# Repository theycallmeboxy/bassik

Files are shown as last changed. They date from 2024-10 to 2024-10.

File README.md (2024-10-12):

# Bassik
*10u ortho alpha uniform traditional stagger keyboard*

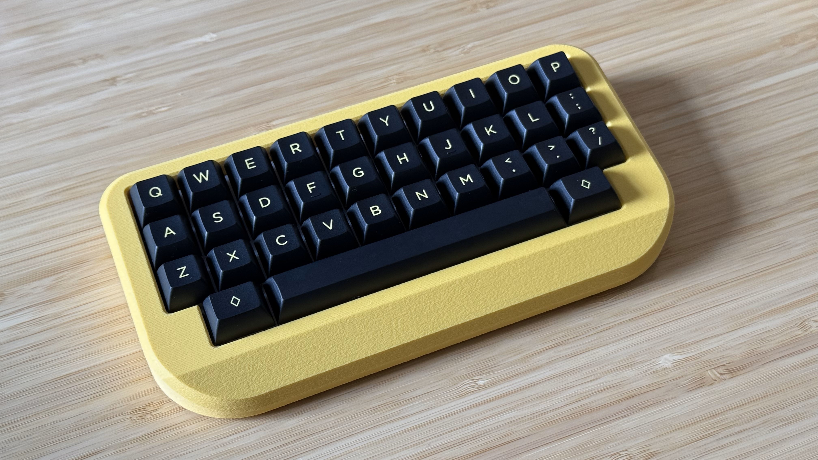
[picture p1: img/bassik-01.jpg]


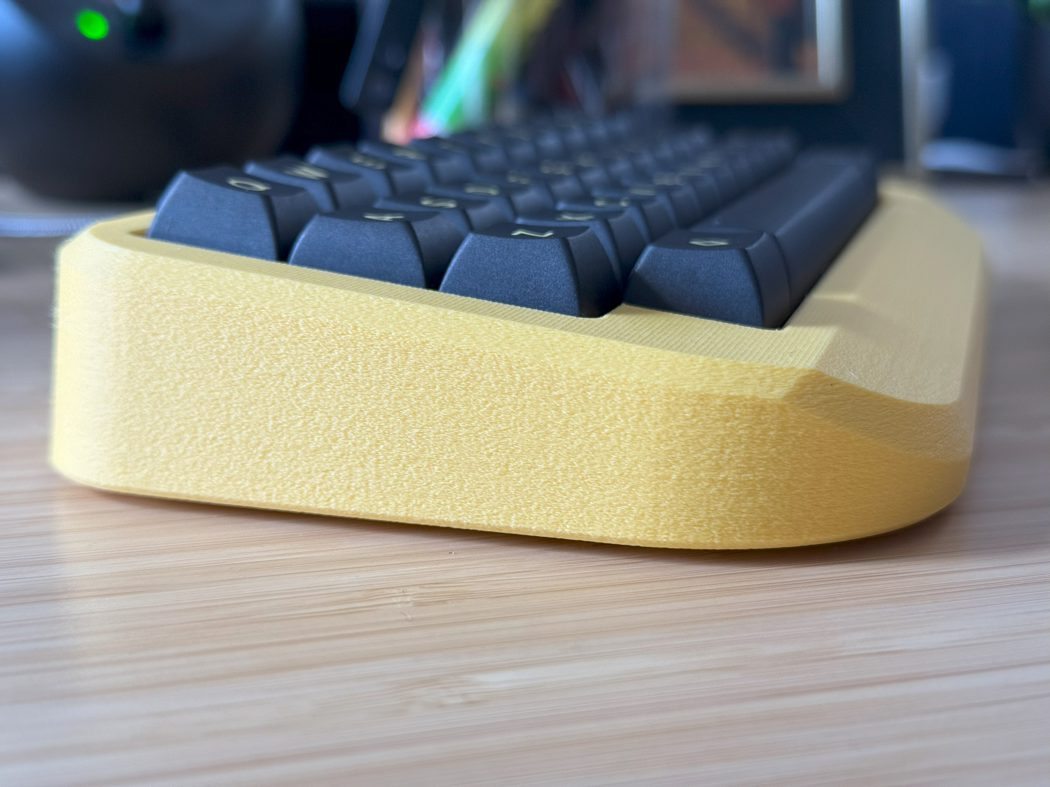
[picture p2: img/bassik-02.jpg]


**[KLE](https://www.keyboard-layout-editor.com/##@_name=Bassik%3B&@=0,0&=0,1&=0,2&=0,3&=0,4&=0,5&=0,6&=0,7&=0,8&=0,9&_x:0.25&c=%2348c763%3B&=1,0%0A%0A%0A0,1&=1,1%0A%0A%0A0,1&=1,2%0A%0A%0A0,1&=1,3%0A%0A%0A0,1&=1,4%0A%0A%0A0,1&=1,5%0A%0A%0A0,1&=1,6%0A%0A%0A0,1&=1,7%0A%0A%0A0,1&=1,8%0A%0A%0A0,1&=1,9%0A%0A%0A0,1%3B&@=1,0%0A%0A%0A0,0&=1,1%0A%0A%0A0,0&=1,2%0A%0A%0A0,0&=1,3%0A%0A%0A0,0&=1,4%0A%0A%0A0,0&=1,5%0A%0A%0A0,0&=1,6%0A%0A%0A0,0&=1,7%0A%0A%0A0,0&=1,8%0A%0A%0A0,0&=1,9%0A%0A%0A0,0&_x:0.25&w:1.5%3B&=2,0%0A%0A%0A0,1&=2,2%0A%0A%0A0,1&=2,3%0A%0A%0A0,1&=2,4%0A%0A%0A0,1&=2,5%0A%0A%0A0,1&=2,6%0A%0A%0A0,1&=2,7%0A%0A%0A0,1&=2,8%0A%0A%0A0,1&_w:1.5%3B&=2,9%0A%0A%0A0,1%3B&@=2,0%0A%0A%0A0,0&=2,1%0A%0A%0A0,0&=2,2%0A%0A%0A0,0&=2,3%0A%0A%0A0,0&=2,4%0A%0A%0A0,0&=2,5%0A%0A%0A0,0&=2,6%0A%0A%0A0,0&=2,7%0A%0A%0A0,0&=2,8%0A%0A%0A0,0&=2,9%0A%0A%0A0,0%3B&@_y:-0.75&x:10.25&w:1.25%3B&=1,0%0A%0A%0A0,2&=1,1%0A%0A%0A0,2&=1,2%0A%0A%0A0,2&=1,3%0A%0A%0A0,2&=1,4%0A%0A%0A0,2&=1,5%0A%0A%0A0,2&=1,6%0A%0A%0A0,2&=1,7%0A%0A%0A0,2&_w:1.75%3B&=1,9%0A%0A%0A0,2%3B&@_y:-0.25&x:0.63&c=%23ffeb8a&w:1.25%3B&=3,0%0A%0A%0A1,0&_w:6.25%3B&=3,4%0A%0A%0A1,0&_x:1.7763568394002505e-15&w:1.25%3B&=3,8%0A%0A%0A1,0%3B&@_y:-0.75&x:10.25&c=%2348c763&w:1.5%3B&=2,0%0A%0A%0A0,2&=2,2%0A%0A%0A0,2&=2,3%0A%0A%0A0,2&=2,4%0A%0A%0A0,2&=2,5%0A%0A%0A0,2&=2,6%0A%0A%0A0,2&=2,7%0A%0A%0A0,2&=2,8%0A%0A%0A0,2&_w:1.5%3B&=2,9%0A%0A%0A0,2%3B&@_x:0.63&c=%23ffeb8a%3B&=3,0%0A%0A%0A1,1&=3,1%0A%0A%0A1,1&=3,2%0A%0A%0A1,1&_w:2.75%3B&=3,4%0A%0A%0A1,1&=3,6%0A%0A%0A1,1&=3,7%0A%0A%0A1,1&_x:1.7763568394002505e-15%3B&=3,8%0A%0A%0A1,1%3B&@_y:-0.75&x:10.25&c=%2348c763&w:1.25%3B&=1,0%0A%0A%0A0,3&=1,1%0A%0A%0A0,3&=1,2%0A%0A%0A0,3&=1,3%0A%0A%0A0,3&=1,4%0A%0A%0A0,3&=1,5%0A%0A%0A0,3&=1,6%0A%0A%0A0,3&=1,7%0A%0A%0A0,3&_w:1.75%3B&=1,9%0A%0A%0A0,3%3B&@_x:0.63&c=%23ffeb8a&w:1.25%3B&=3,0%0A%0A%0A1,2&=3,1%0A%0A%0A1,2&_w:2.25%3B&=3,3%0A%0A%0A1,2&_w:2%3B&=3,5%0A%0A%0A1,2&=3,7%0A%0A%0A1,2&_x:1.7763568394002505e-15&w:1.25%3B&=3,8%0A%0A%0A1,2&_x:0.8699999999999992&c=%2348c763&w:1.75%3B&=2,0%0A%0A%0A0,3&=2,2%0A%0A%0A0,3&=2,3%0A%0A%0A0,3&=2,4%0A%0A%0A0,3&=2,5%0A%0A%0A0,3&=2,6%0A%0A%0A0,3&=2,7%0A%0A%0A0,3&=2,8%0A%0A%0A0,3&_w:1.25%3B&=2,9%0A%0A%0A0,3)**

## Production Files:
> [!CAUTION]
> I will assume no responsibility for any cost, damage, or sads resulting from trying to make one of my dumb projects. This project has no implicit support, neither moral nor technical.
> 
> **I'm not a doctor. This is not medical advice. I'm also only a network engineer. You assume all liability in using or reproducing these files.**

Case:
- [Case .stl file](https://github.com/theycallmeboxy/bassik/blob/main/models/case/bassik-case.stl)
- [Case .step file](https://github.com/theycallmeboxy/bassik/blob/main/models/case/bassik-case.step)

Plate:
- [Ortho stagger 6.25u spacebar plate .dxf file](https://github.com/theycallmeboxy/bassik/blob/main/models/plate/ortho-625.dxf)
- [Ortho stagger 2.75u spacebar plate .dxf file](https://github.com/theycallmeboxy/bassik/blob/main/models/plate/ortho-275.dxf)
- [Ortho stagger 2.25-2.00 spacebars plate .dxf file](https://github.com/theycallmeboxy/bassik/blob/main/models/plate/ortho-225200.dxf)
- [Ortho stagger universal plate .dxf file](https://github.com/theycallmeboxy/bassik/blob/main/models/plate/ortho-universal.dxf)
- [Alpha stagger 6.25u spacebar plate .dxf file](https://github.com/theycallmeboxy/bassik/blob/main/models/plate/alpha-625.dxf)
- [Alpha stagger 2.75u spacebar plate .dxf file](https://github.com/theycallmeboxy/bassik/blob/main/models/plate/alpha-275.dxf)
- [Alpha stagger 2.25-2.00 spacebars plate .dxf file](https://github.com/theycallmeboxy/bassik/blob/main/models/plate/alpha-225200.dxf)
- [Alpha stagger universal plate .dxf file](https://github.com/theycallmeboxy/bassik/blob/main/models/plate/alpha-universal.dxf)
- [Uniform stagger 6.25u spacebar plate .dxf file](https://github.com/theycallmeboxy/bassik/blob/main/models/plate/uni-625.dxf)
- [Uniform stagger 2.75u spacebar plate .dxf file](https://github.com/theycallmeboxy/bassik/blob/main/models/plate/uni-275.dxf)
- [Uniform stagger 2.25-2.00 spacebars plate .dxf file](https://github.com/theycallmeboxy/bassik/blob/main/models/plate/uni-225200.dxf)
- [Uniform stagger universal plate .dxf file](https://github.com/theycallmeboxy/bassik/blob/main/models/plate/uni-universal.dxf)
- [Traditional stagger 6.25u spacebar plate .dxf file](https://github.com/theycallmeboxy/bassik/blob/main/models/plate/trad-625.dxf)
- [Traditional stagger 2.75u spacebar plate .dxf file](https://github.com/theycallmeboxy/bassik/blob/main/models/plate/uni-275.dxf)
- [Traditional stagger 2.25-2.00 spacebars plate .dxf file](https://github.com/theycallmeboxy/bassik/blob/main/models/plate/trad-225200.dxf)
- [Traditional stagger universal plate .dxf file](https://github.com/theycallmeboxy/bassik/blob/main/models/plate/trad-universal.dxf)

PCB:
> [!NOTE]
> Version 1 was produced (as prototype 1) without any identified issues.  The gerbers were regenerated to indicate version 1 on the silk and have retained the original BOM and positions files.  I have not produced these files yet, but they should be good to go.

- [PCB gerbers .zip file](https://github.com/theycallmeboxy/bassik/blob/main/pcb/bassik%20v1/production/bassik.zip)
- [BOM .csv file](https://github.com/theycallmeboxy/bassik/blob/main/pcb/bassik%20v1/production/bom.csv)
- [Positions .csv file](https://github.com/theycallmeboxy/bassik/blob/main/pcb/bassik%20v1/production/positions.csv)

Firmware:
- [VIAL Firmware .bin file](https://github.com/theycallmeboxy/bassik/blob/main/firmware/vial/binary/boxy_bassik_vial.bin)
  
## Build Notes:

I have made with FDM to good effect.

**Additional materials:**
 
  - About 16" of .139" (3.53mm) cross section o-ring cord [like this 50A cord](https://www.theoringstore.com/store/index.php?main_page=product_info&cPath=117_527&products_id=18618) or [this 70A cord](https://www.theoringstore.com/store/index.php?main_page=product_info&cPath=117_119&products_id=5058); if you don't want to buy bulk cord, you can cut up an o-ring of like 6" or bigger diameter.
  - 4 SKUF feet like these  [like these](https://keeb.io/products/skuf-silicone-rubber-keyboard-feet).

**Build instructions:**

1. Apply feet to the cutouts.
2. Install stabs if you're into that. 
3. Install switches into the plate and PCB.
4. Solder it up.
5. Friction fit the o-ring cord between the plate and PCB in the positions highlighted in red:

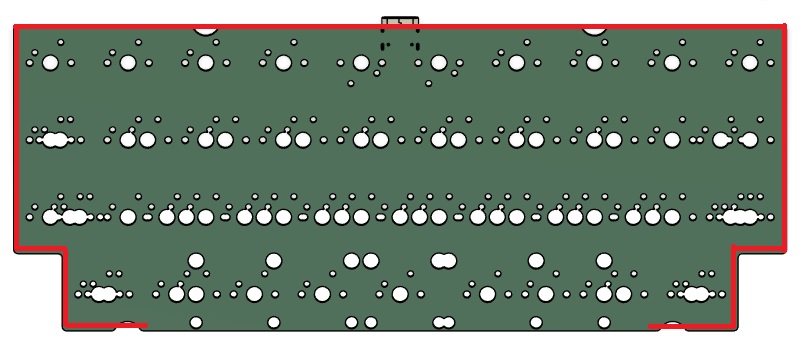
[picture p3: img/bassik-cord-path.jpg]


6. Insert the assembled PCB USB port first into the case at an angle, aligning the port with the cutout.
7. Press the top of the PCB in place, then press in the bottom side (if your cord isn't fully seated, sticks out on the corners, or otherwise catches going in, grab some tweezers and help it stay in between the plate and PCB). 
8. If you need to remove the PCB, pull a few caps off and use a switch puller on the soldered switches.

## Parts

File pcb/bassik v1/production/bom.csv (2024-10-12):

Designator | Footprint | Quantity | Value | LCSC Part #
BOOT1, RST1 | SW_SPST_TL3342 | 2 | SW_SPST | C318884
C1, C3, C4, C5, C6, C7, C8 | 0402 | 7 | 100nF | C1525
C10, C9 | 0402 | 2 | 1uF | C52923
C2 | 0603 | 1 | 10uF | C19702
D1, D10, D11, D12, D13, D14, D15, D16, D17, D18, D19, D2, D20, D21, D22, D23, D24, D25, D26, D27, D28, D29, D3, D30, D31, D32, D33, D34, D35, D36, D37, D38, D39, D4, D5, D6, D7, D8, D9 | D_SOD-123 | 39 | D | C81598
F1 | 1206 | 1 | 500mA | C369160
J1 | USB_C_Receptacle_HRO_TYPE-C-31-M-12 | 1 | USB_C_Receptacle_USB2.0 | C165948
R1, R2, R3, R4 | 0402 | 4 | 5.1k | C25905
U1 | LQFP-48_7x7mm_P0.5mm | 1 | STM32F072CBT6 | C81720
U2 | SOT-143 | 1 | PRTR5V0U2X | C2827688
U3 | SOT-23 | 1 | XC6206PxxxMR-Regulator_Linear | C5446

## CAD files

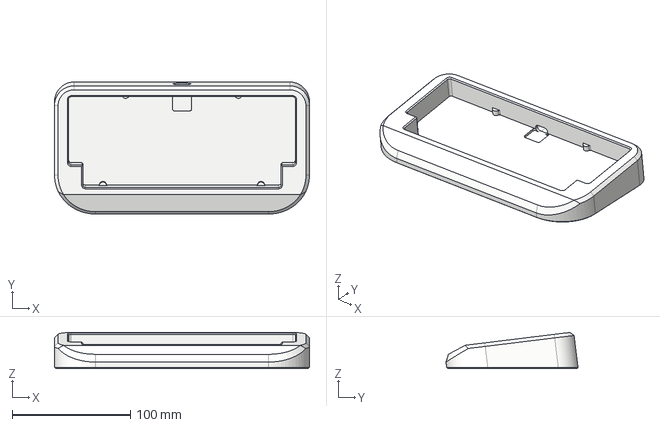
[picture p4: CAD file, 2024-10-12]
models/case/bassik-case.step
215.6 x 111.6 x 30.6 mm

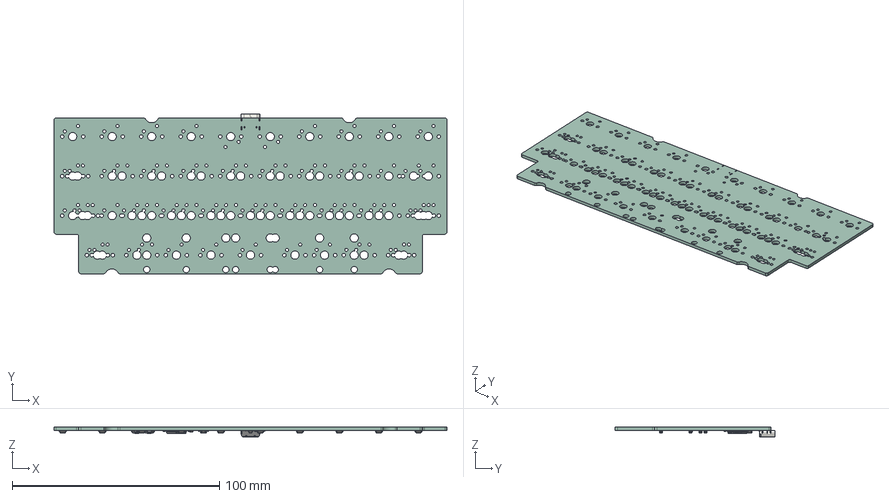
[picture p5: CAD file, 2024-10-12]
models/pcb/bassik.step
189.5 x 76.9 x 4.85 mm
C_0402_1005Metric x 9
D_SOD_123 x 39
R_0402_1005Metric x 4
SW_SPST_TL3342 x 2
SOT_143
CON_TYPE-C-31-M-12 v3
C_0603_1608Metric
SOT_23
Fuse_1206_3216Metric
LQFP_48_7x7mm_P05mm
bassik_PCB

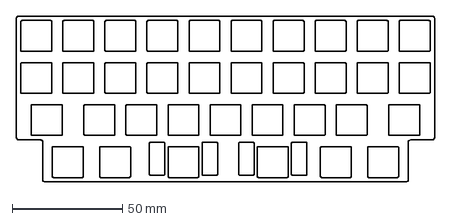
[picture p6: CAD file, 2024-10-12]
models/plate/alpha-225200.dxf
189.4 x 75.2 mm

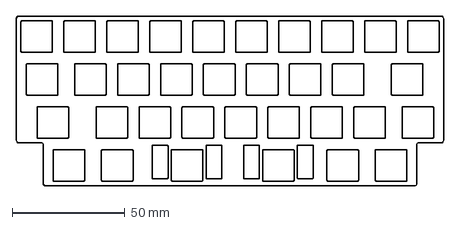
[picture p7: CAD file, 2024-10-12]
models/plate/trad-225200.dxf
189.4 x 75.2 mm

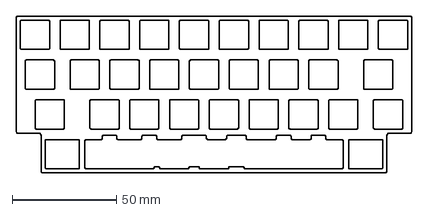
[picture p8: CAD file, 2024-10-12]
models/plate/trad-universal.dxf
189.4 x 75.2 mm

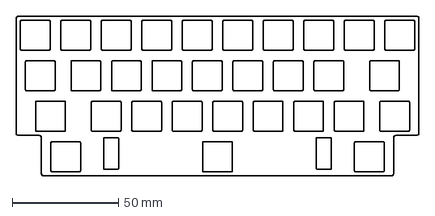
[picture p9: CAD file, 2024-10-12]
models/plate/trad-625.dxf
189.4 x 75.2 mm

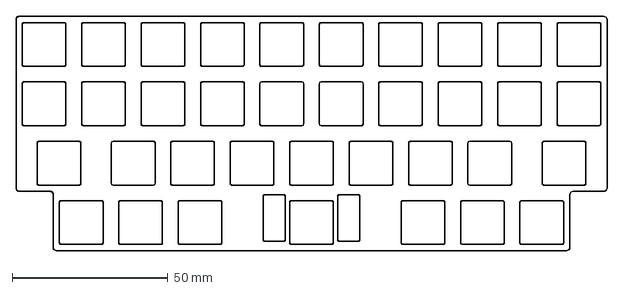
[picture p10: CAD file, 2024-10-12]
models/plate/alpha-275.dxf
189.4 x 75.2 mm

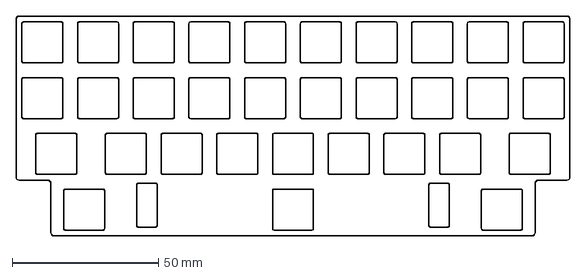
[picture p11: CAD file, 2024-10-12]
models/plate/alpha-625.dxf
189.4 x 75.2 mm

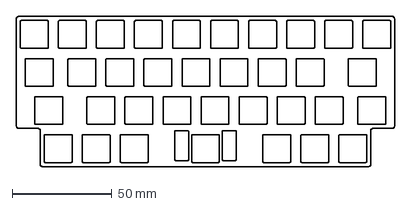
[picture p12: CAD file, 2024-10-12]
models/plate/trad-275.dxf
189.4 x 75.2 mm

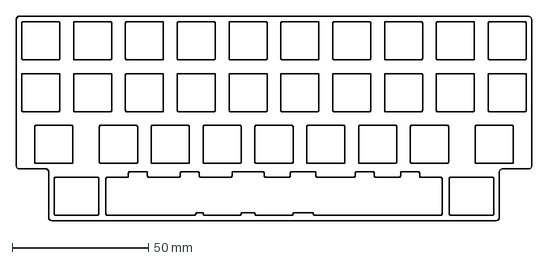
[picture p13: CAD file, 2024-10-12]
models/plate/alpha-universal.dxf
189.4 x 75.2 mm

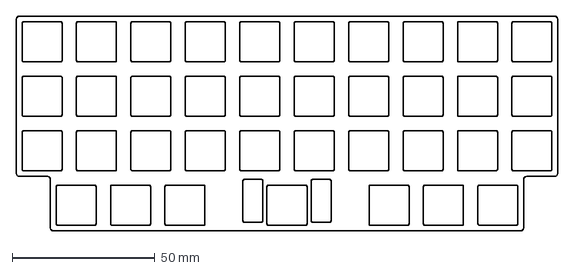
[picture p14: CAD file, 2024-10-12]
models/plate/ortho-275.dxf
189.4 x 75.2 mm

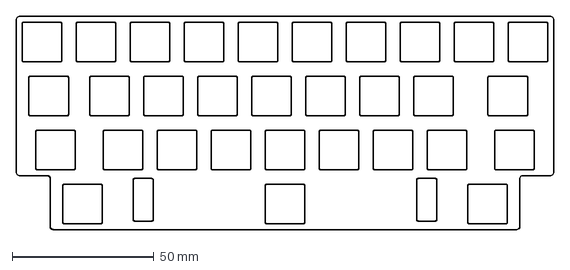
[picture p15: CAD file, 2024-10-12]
models/plate/uni-625.dxf
189.4 x 75.2 mm

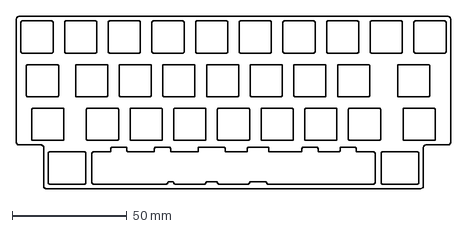
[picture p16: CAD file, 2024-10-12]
models/plate/uni-universal.dxf
189.4 x 75.2 mm

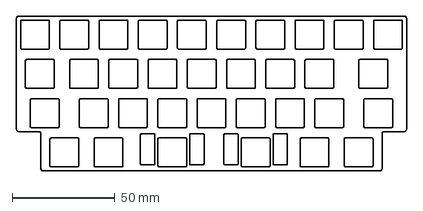
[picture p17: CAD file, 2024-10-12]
models/plate/uni-225200.dxf
189.4 x 75.2 mm

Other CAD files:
models/plate/ortho-225200.dxf
models/plate/ortho-universal.dxf
models/plate/ortho-625.dxf
models/plate/uni-275.dxf
models/case/bassik-case.stl

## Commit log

2024-10-12 fire ze missles
    [bassik-case.step, bassik-case.stl, bassik.kicad_sch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]
2024-10-12 i am smart
    [uni-200225.dxf, uni-275.dxf, uni-625.dxf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]
2024-10-12 plate spinning
    [alpha-225200.dxf, alpha-275.dxf, alpha-625.dxf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]
